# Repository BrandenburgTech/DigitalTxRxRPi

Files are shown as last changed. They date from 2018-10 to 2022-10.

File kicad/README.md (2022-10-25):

v1_3 - Digital Transceiver for the Raspberry Pi with the AX5043

v1_3_5 - Digital Transceiver for the Raspberry Pi with the AX5243

v2_0 - Digital Transceiver for the Raspberry Pi with the AX5043, power amplifier, and GPS module

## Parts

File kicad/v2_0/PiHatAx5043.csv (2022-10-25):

Source: | /home/jbrandenburg/src/git/maker/PiHatAx5043/kicad/PiHatAx5043.sch
Date: | Fri 19 Oct 2018 04:19:05 PM CDT
Tool: | Eeschema 5.0.1-33cea8e~67~ubuntu18.04.1
Generator: | /usr/share/kicad/plugins/bom_csv_grouped_by_value.py
Component Count: | 78
Individual Components:
Item | Qty | Reference(s) | Value | LibPart | Footprint | Datasheet | Description | Height | Manufacturer_Name | Manufacturer_Part_Number | RS Part Number | Supplier_Name
 |  | C1 | DNP | Device:C | Capacitor_SMD:C_0603_1608Metric
 |  | C2 | DNP | Device:C | Capacitor_SMD:C_0603_1608Metric
 |  | C3 | DNP | Device:C | Capacitor_SMD:C_0603_1608Metric
 |  | C4 | 5p1 | Device:C | Capacitor_SMD:C_0603_1608Metric
 |  | C5 | 11p | Device:C | Capacitor_SMD:C_0603_1608Metric
 |  | C6 | 5p6 | Device:C | Capacitor_SMD:C_0603_1608Metric
 |  | C7 | 4p3 | Device:C | Capacitor_SMD:C_0603_1608Metric
 |  | C8 | 4p3 | Device:C | Capacitor_SMD:C_0603_1608Metric
 |  | C9 | 10n | Device:C | Capacitor_SMD:C_0603_1608Metric
 |  | C10 | 10n | Device:C | Capacitor_SMD:C_0603_1608Metric
 |  | C11 | 10n | Device:C | Capacitor_SMD:C_0603_1608Metric
 |  | C12 | 100n | Device:C | Capacitor_SMD:C_0603_1608Metric
 |  | C13 | 4p3 | Device:C | Capacitor_SMD:C_0603_1608Metric | ~
 |  | C14 | 5p6 | Device:C | Capacitor_SMD:C_0603_1608Metric | ~
 |  | C15 | DNP | Device:C | Capacitor_SMD:C_0603_1608Metric | ~
 |  | C16 | 6p8 | Device:C | Capacitor_SMD:C_0603_1608Metric | ~
 |  | C17 | DNP | Device:C | Capacitor_SMD:C_0603_1608Metric | ~
 |  | C18 | DNP | Device:C | Capacitor_SMD:C_0603_1608Metric | ~
 |  | C19 | DNP | Device:C | Capacitor_SMD:C_0603_1608Metric | ~
 |  | C20 | 100p | Device:C | Capacitor_SMD:C_0603_1608Metric | ~
 |  | C21 | 1u | Device:C | Capacitor_SMD:C_0603_1608Metric | ~
 |  | C22 | 1u | Device:C | Capacitor_SMD:C_0603_1608Metric | ~
 |  | C23 | 470p | Device:C | Capacitor_SMD:C_0603_1608Metric | ~
 |  | C24 | 4u7 | Device:C | Capacitor_SMD:C_0603_1608Metric | ~
 |  | C25 | 3p9 | Device:C | Capacitor_SMD:C_0603_1608Metric | ~
 |  | C26 | 10p | Device:C | Capacitor_SMD:C_0603_1608Metric | ~
 |  | C27 | 3p3 | Device:C | Capacitor_SMD:C_0603_1608Metric | ~
 |  | C28 | 11p | Device:C | Capacitor_SMD:C_0603_1608Metric | ~
 |  | C29 | 3p3 | Device:C | Capacitor_SMD:C_0603_1608Metric | ~
 |  | C30 | 10n | Device:C | Capacitor_SMD:C_0603_1608Metric | ~
 |  | C31 | 47p | Device:C | Capacitor_SMD:C_0603_1608Metric | ~
 |  | C32 | NP | Device:C | Capacitor_SMD:C_0603_1608Metric | ~
 |  | C33 | NP | Device:C | Capacitor_SMD:C_0603_1608Metric | ~
 |  | D1 | LED | Device:LED | LED_SMD:LED_0603_1608Metric
 |  | J1 | Conn_01x02_Male | Connector:Conn_01x02_Male | Connector_PinHeader_2.54mm:PinHeader_1x02_P2.54mm_Vertical | ~
 |  | J2 | Conn_01x02_Male | Connector:Conn_01x02_Male | Connector_PinHeader_2.54mm:PinHeader_1x02_P2.54mm_Vertical | ~
 |  | J3 | Conn_01x02_Male | Connector:Conn_01x02_Male | Connector_PinHeader_2.54mm:PinHeader_1x02_P2.54mm_Vertical | ~
 |  | J4 | Conn_01x02_Male | Connector:Conn_01x02_Male | Connector_PinHeader_2.54mm:PinHeader_1x02_P2.54mm_Vertical | ~
 |  | J5 | Conn_01x03_Male | Connector:Conn_01x03_Male | Connector_PinHeader_2.54mm:PinHeader_1x03_P2.54mm_Vertical | ~
 |  | J6 | Conn_01x02_Male | Connector:Conn_01x02_Male | Connector_PinHeader_2.54mm:PinHeader_1x02_P2.54mm_Vertical | ~
 |  | L1 | 0R | Device:L | Inductor_SMD:L_0603_1608Metric
 |  | L2 | 27n | Device:L | Inductor_SMD:L_0603_1608Metric
 |  | L3 | 27n | Device:L | Inductor_SMD:L_0603_1608Metric
 |  | L4 | 43n | Device:L | Inductor_SMD:L_0603_1608Metric
 |  | L5 | 43n | Device:L | Inductor_SMD:L_0603_1608Metric
 |  | L6 | 100n | Device:L | Inductor_SMD:L_0603_1608Metric
 |  | L7 | 100n | Device:L | Inductor_SMD:L_0603_1608Metric
 |  | L8 | 0R | Device:L | Inductor_SMD:L_0603_1608Metric
 |  | L9 | 43n | Device:L | Inductor_SMD:L_0603_1608Metric | ~
 |  | L10 | 100n | Device:L | Inductor_SMD:L_0603_1608Metric | ~
 |  | L11 | 4n7 | Device:L | Inductor_SMD:L_0603_1608Metric | ~
 |  | L12 | 0R | Device:L | Inductor_SMD:L_0603_1608Metric | ~
 |  | L13 | 18n | Device:L | Inductor_SMD:L_0603_1608Metric | ~
 |  | L14 | 1n2 | Device:L | Inductor_SMD:L_0603_1608Metric | ~
 |  | L15 | 12n | Device:L | Inductor_SMD:L_0603_1608Metric | ~
 |  | L16 | 3n9 | Device:L | Inductor_SMD:L_0603_1608Metric | ~
 |  | L17 | 12n | Device:L | Inductor_SMD:L_0603_1608Metric | ~
 |  | L18 | 22n | Device:L | Inductor_SMD:L_0603_1608Metric | ~
 |  | L19 | 22n | Device:L | Inductor_SMD:L_0603_1608Metric | ~
 |  | L20 | 27n | Device:L | Inductor_SMD:L_0603_1608Metric | ~
 |  | P1 | SMA | Connector:Conn_Coaxial | Connector_Coaxial:SMA_Amphenol_901-144_Vertical
 |  | P2 | CONN_13X2 | Connector_Generic:Conn_02x13_Odd_Even | Connector_PinHeader_2.54mm:PinHeader_2x13_P2.54mm_Vertical
 |  | P3 | CONN_01X06 | Connector:Conn_01x06_Male | Connector_PinHeader_2.54mm:PinHeader_1x06_P2.54mm_Vertical
 |  | P4 | SMA | Connector:Conn_Coaxial | Connector_Coaxial:SMA_Amphenol_901-144_Vertical
 |  | P5 | SMA | Connector:Conn_Coaxial | Connector_Coaxial:SMA_Amphenol_901-144_Vertical
 |  | R1 | 0R | Device:R | Resistor_SMD:R_0603_1608Metric
 |  | R2 | 0R | Device:R | Resistor_SMD:R_0603_1608Metric
 |  | R3 | 4k7 | Device:R | Resistor_SMD:R_0603_1608Metric
 |  | R4 | 4k7 | Device:R | Resistor_SMD:R_0603_1608Metric
 |  | R5 | 200 | Device:R | Resistor_SMD:R_0603_1608Metric
 |  | R6 | 330 | Device:R | Resistor_SMD:R_0603_1608Metric | ~
 |  | R7 | 1k5 | Device:R | Resistor_SMD:R_0603_1608Metric | ~
 |  | R8 | 10 | Device:R | Resistor_SMD:R_0603_1608Metric | ~
 |  | U1 | AX5043 | ax5043:AX5043-1-TA05 | ax5043:QFN50P500X500X95-29N | http://docs-europe.electrocomponents.com/webdocs/14ae/0900766b814aed64.pdf | AX5043 27-1050MHz RF Transceiver AX5043-1-TA05, RF Transceiver 27 1050MHz, AFSK, ASK, FM, FSK, GFSK, GMSK, MSK, PSK, QFSK, 1.8 3.6 V | 0.95 | ON Semiconductor | AX5043-1-TA05 | 1249950 | RS
 |  | U2 | MAX31725 | max31725:MAX31725 | Package_DFN_QFN:DFN-8-1EP_3x3mm_P0.65mm_EP1.55x2.4mm
 |  | U3 | MMZ09312BT1 | nxp:MMZ09312BT1 | Package_DFN_QFN:QFN-12-1EP_3x3mm_P0.5mm_EP1.65x1.65mm_ThermalVias
 |  | U4 | MAX-M8 | ublox:MAX-M8 | MAX-M8:MAX-M8
 |  | Y1 | 16M | Device:Crystal_GND24 | ecx-42-smd-crystal:Crystal_SMD_ECX42-4pin_4.0x2.5mm
Collated Components:
Item | Qty | Reference(s) | Value | LibPart | Footprint | Datasheet | Description | Height | Manufacturer_Name | Manufacturer_Part_Number | RS Part Number | Supplier_Name
1 | 7 | C1, C2, C3, C15, C17, C18, C19 | DNP | Device:C | Capacitor_SMD:C_0603_1608Metric | ~
2 | 1 | C4 | 5p1 | Device:C | Capacitor_SMD:C_0603_1608Metric
3 | 2 | C5, C28 | 11p | Device:C | Capacitor_SMD:C_0603_1608Metric | ~
4 | 2 | C6, C14 | 5p6 | Device:C | Capacitor_SMD:C_0603_1608Metric | ~
5 | 3 | C7, C8, C13 | 4p3 | Device:C | Capacitor_SMD:C_0603_1608Metric | ~
6 | 4 | C9, C10, C11, C30 | 10n | Device:C | Capacitor_SMD:C_0603_1608Metric | ~
7 | 1 | C12 | 100n | Device:C | Capacitor_SMD:C_0603_1608Metric
8 | 1 | C16 | 6p8 | Device:C | Capacitor_SMD:C_0603_1608Metric | ~
9 | 1 | C20 | 100p | Device:C | Capacitor_SMD:C_0603_1608Metric | ~
10 | 2 | C21, C22 | 1u | Device:C | Capacitor_SMD:C_0603_1608Metric | ~
11 | 1 | C23 | 470p | Device:C | Capacitor_SMD:C_0603_1608Metric | ~
12 | 1 | C24 | 4u7 | Device:C | Capacitor_SMD:C_0603_1608Metric | ~
13 | 1 | C25 | 3p9 | Device:C | Capacitor_SMD:C_0603_1608Metric | ~
14 | 1 | C26 | 10p | Device:C | Capacitor_SMD:C_0603_1608Metric | ~
15 | 2 | C27, C29 | 3p3 | Device:C | Capacitor_SMD:C_0603_1608Metric | ~
16 | 1 | C31 | 47p | Device:C | Capacitor_SMD:C_0603_1608Metric | ~
17 | 2 | C32, C33 | NP | Device:C | Capacitor_SMD:C_0603_1608Metric | ~
18 | 1 | D1 | LED | Device:LED | LED_SMD:LED_0603_1608Metric
19 | 5 | J1, J2, J3, J4, J6 | Conn_01x02_Male | Connector:Conn_01x02_Male | Connector_PinHeader_2.54mm:PinHeader_1x02_P2.54mm_Vertical | ~
20 | 1 | J5 | Conn_01x03_Male | Connector:Conn_01x03_Male | Connector_PinHeader_2.54mm:PinHeader_1x03_P2.54mm_Vertical | ~
21 | 3 | L1, L8, L12 | 0R | Device:L | Inductor_SMD:L_0603_1608Metric | ~
22 | 3 | L2, L3, L20 | 27n | Device:L | Inductor_SMD:L_0603_1608Metric | ~
23 | 3 | L4, L5, L9 | 43n | Device:L | Inductor_SMD:L_0603_1608Metric | ~
24 | 3 | L6, L7, L10 | 100n | Device:L | Inductor_SMD:L_0603_1608Metric | ~
25 | 1 | L11 | 4n7 | Device:L | Inductor_SMD:L_0603_1608Metric | ~
26 | 1 | L13 | 18n | Device:L | Inductor_SMD:L_0603_1608Metric | ~
27 | 1 | L14 | 1n2 | Device:L | Inductor_SMD:L_0603_1608Metric | ~
28 | 2 | L15, L17 | 12n | Device:L | Inductor_SMD:L_0603_1608Metric | ~
29 | 1 | L16 | 3n9 | Device:L | Inductor_SMD:L_0603_1608Metric | ~
30 | 2 | L18, L19 | 22n | Device:L | Inductor_SMD:L_0603_1608Metric | ~
31 | 3 | P1, P4, P5 | SMA | Connector:Conn_Coaxial | Connector_Coaxial:SMA_Amphenol_901-144_Vertical
32 | 1 | P2 | CONN_13X2 | Connector_Generic:Conn_02x13_Odd_Even | Connector_PinHeader_2.54mm:PinHeader_2x13_P2.54mm_Vertical
33 | 1 | P3 | CONN_01X06 | Connector:Conn_01x06_Male | Connector_PinHeader_2.54mm:PinHeader_1x06_P2.54mm_Vertical
34 | 2 | R1, R2 | 0R | Device:R | Resistor_SMD:R_0603_1608Metric
35 | 2 | R3, R4 | 4k7 | Device:R | Resistor_SMD:R_0603_1608Metric
36 | 1 | R5 | 200 | Device:R | Resistor_SMD:R_0603_1608Metric
37 | 1 | R6 | 330 | Device:R | Resistor_SMD:R_0603_1608Metric | ~
38 | 1 | R7 | 1k5 | Device:R | Resistor_SMD:R_0603_1608Metric | ~
39 | 1 | R8 | 10 | Device:R | Resistor_SMD:R_0603_1608Metric | ~
40 | 1 | U1 | AX5043 | ax5043:AX5043-1-TA05 | ax5043:QFN50P500X500X95-29N | http://docs-europe.electrocomponents.com/webdocs/14ae/0900766b814aed64.pdf | AX5043 27-1050MHz RF Transceiver AX5043-1-TA05, RF Transceiver 27 1050MHz, AFSK, ASK, FM, FSK, GFSK, GMSK, MSK, PSK, QFSK, 1.8 3.6 V | 0.95 | ON Semiconductor | AX5043-1-TA05 | 1249950 | RS
41 | 1 | U2 | MAX31725 | max31725:MAX31725 | Package_DFN_QFN:DFN-8-1EP_3x3mm_P0.65mm_EP1.55x2.4mm
42 | 1 | U3 | MMZ09312BT1 | nxp:MMZ09312BT1 | Package_DFN_QFN:QFN-12-1EP_3x3mm_P0.5mm_EP1.65x1.65mm_ThermalVias
43 | 1 | U4 | MAX-M8 | ublox:MAX-M8 | MAX-M8:MAX-M8
44 | 1 | Y1 | 16M | Device:Crystal_GND24 | ecx-42-smd-crystal:Crystal_SMD_ECX42-4pin_4.0x2.5mm

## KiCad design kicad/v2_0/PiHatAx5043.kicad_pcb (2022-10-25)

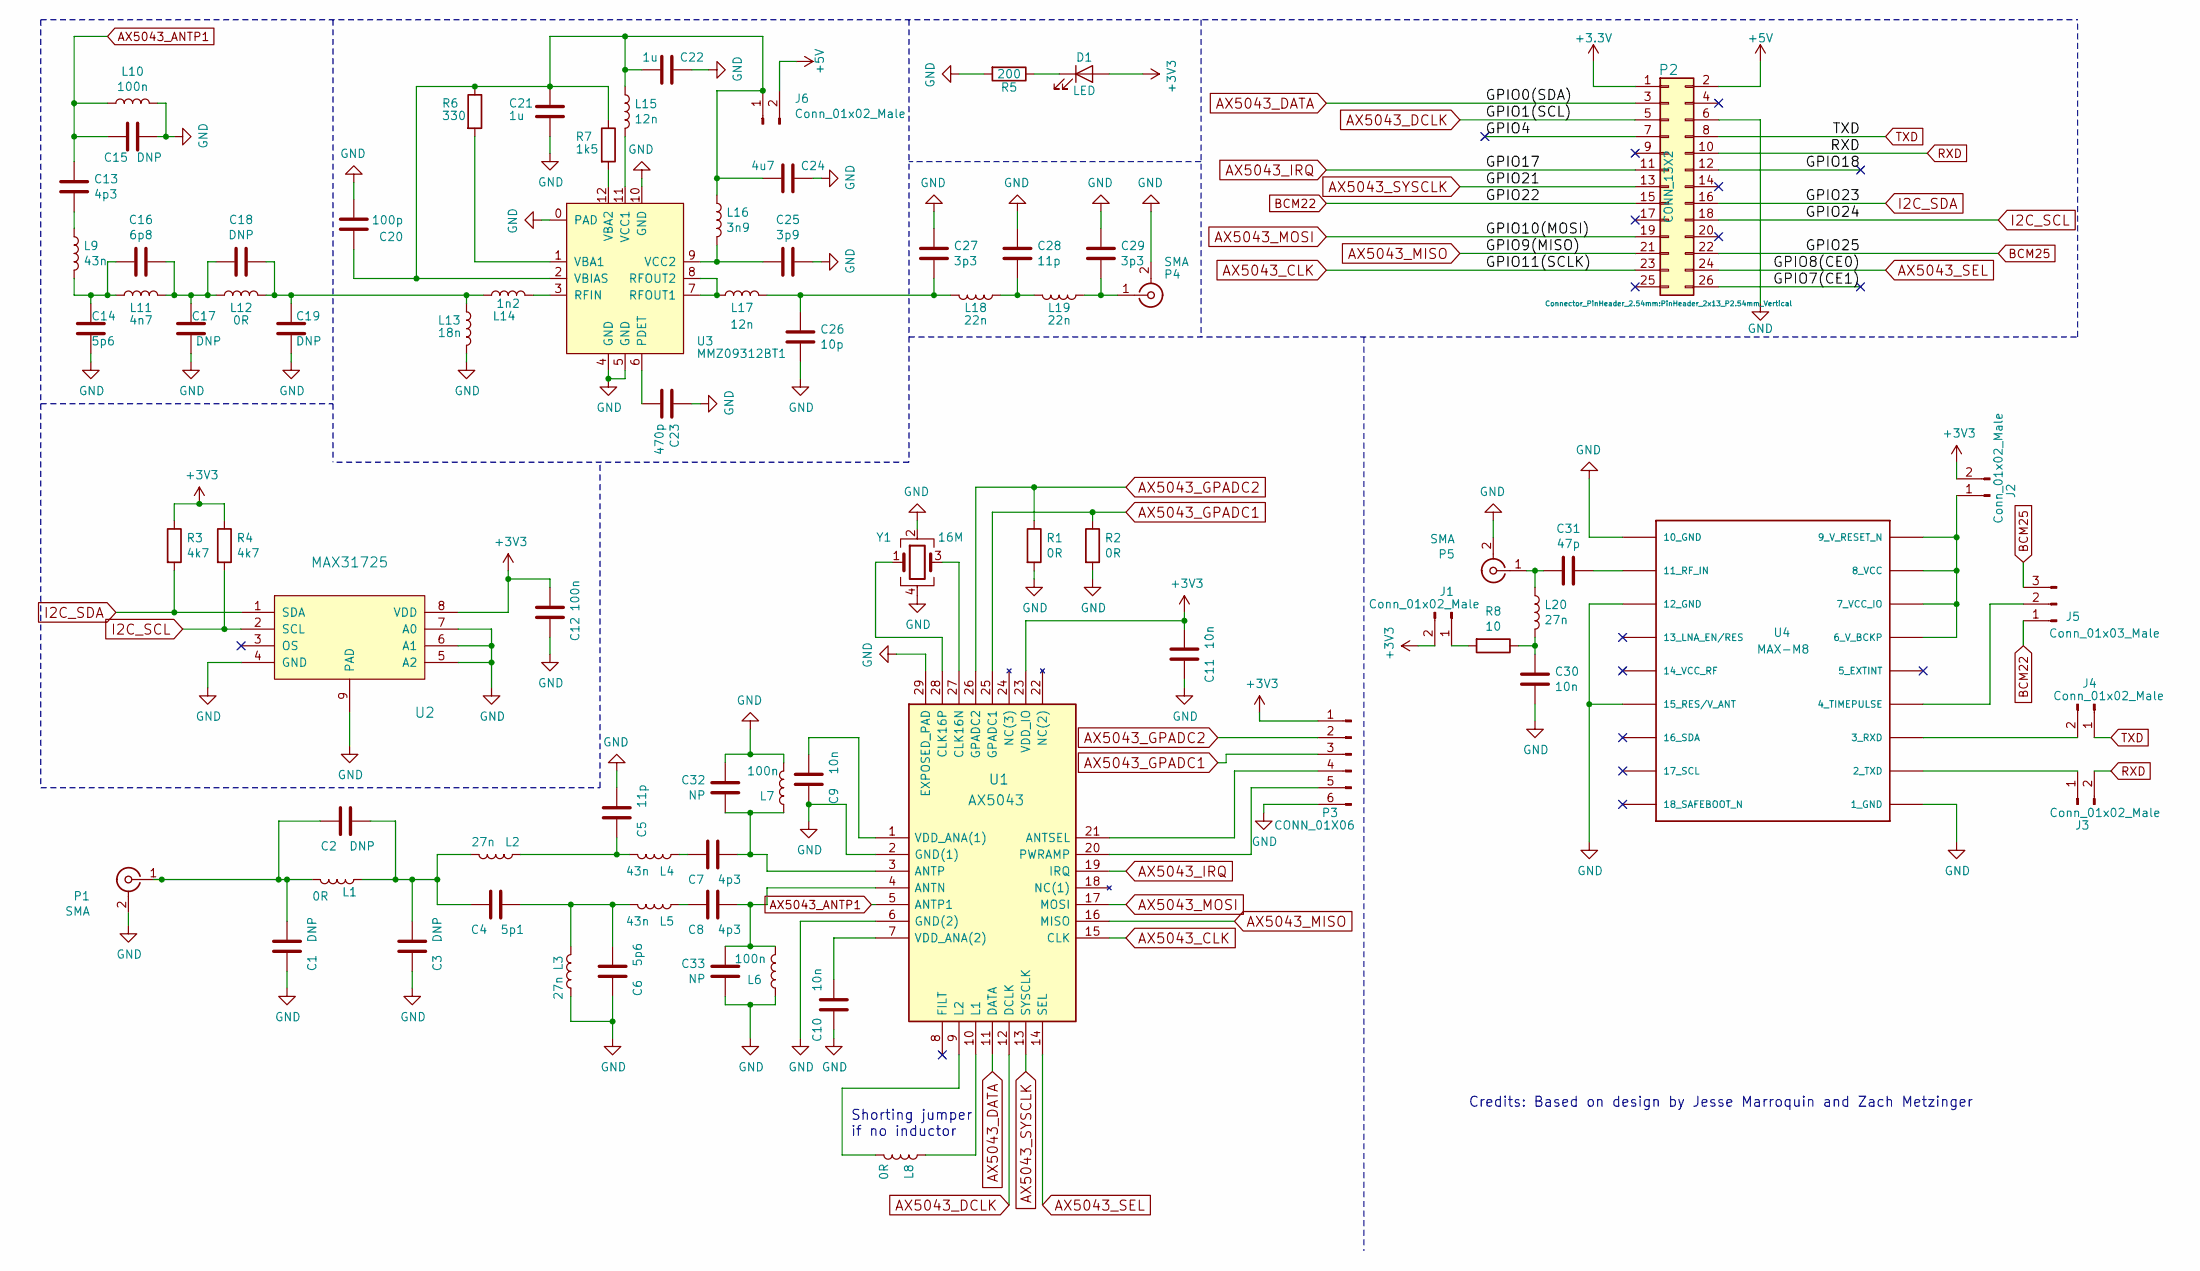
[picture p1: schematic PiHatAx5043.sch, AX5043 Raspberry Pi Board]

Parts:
C1, C2, C3, C15, C17, C18, C19: DNP; C_0603_1608Metric
C4: 5p1; C_0603_1608Metric
C5, C28: 11p; C_0603_1608Metric
C6, C14: 5p6; C_0603_1608Metric
C7, C8, C13: 4p3; C_0603_1608Metric
C9, C10, C11, C30: 10n; C_0603_1608Metric
C12: 100n; C_0603_1608Metric
C16: 6p8; C_0603_1608Metric
C20: 100p; C_0603_1608Metric
C21, C22: 1u; C_0603_1608Metric
C23: 470p; C_0603_1608Metric
C24: 4u7; C_0603_1608Metric
C25: 3p9; C_0603_1608Metric
C26: 10p; C_0603_1608Metric
C27, C29: 3p3; C_0603_1608Metric
C31: 47p; C_0603_1608Metric
C32, C33: NP; C_0603_1608Metric
D1: LED; LED_0603_1608Metric
J1, J2, J3, J4, J6: Conn_01x02_Male; PinHeader_1x02_P2.54mm_Vertical
J5: Conn_01x03_Male; PinHeader_1x03_P2.54mm_Vertical
L1, L8, L12: 0R; L_0603_1608Metric
L2, L3, L20: 27n; L_0603_1608Metric
L4, L5, L9: 43n; L_0603_1608Metric
L6, L7, L10: 100n; L_0603_1608Metric
L11: 4n7; L_0603_1608Metric
L13: 18n; L_0603_1608Metric
L14: 1n2; L_0603_1608Metric
L15, L17: 12n; L_0603_1608Metric
L16: 3n9; L_0603_1608Metric
L18, L19: 22n; L_0603_1608Metric
P1, P4, P5: SMA; SMA_Amphenol_901-144_Vertical
P2: CONN_13X2; PinHeader_2x13_P2.54mm_Vertical
P3: CONN_01X06; PinHeader_1x06_P2.54mm_Vertical
R1, R2: 0R; R_0603_1608Metric
R3, R4: 4k7; R_0603_1608Metric
R5: 200; R_0603_1608Metric
R6: 330; R_0603_1608Metric
R7: 1k5; R_0603_1608Metric
R8: 10; R_0603_1608Metric
U1: AX5043; QFN50P500X500X95-29N
U2: MAX31725; DFN-8-1EP_3x3mm_P0.65mm_EP1.55x2.4mm
U3: MMZ09312BT1; QFN-12-1EP_3x3mm_P0.5mm_EP1.65x1.65mm_ThermalVias
U4: MAX-M8
Y1: 16M; Crystal_SMD_ECX42-4pin_4.0x2.5mm

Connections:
+5V: J6.2, P2.2
/GPIO4: P2.7
/GPIO7(CE1): P2.26
/GPIO18: P2.12
AX5043_ANTP1: C13.1, C15.2, L10.1, U1.5 (ANTP1)
AX5043_CLK: P2.23, U1.15 (CLK)
AX5043_DATA: P2.3, U1.11 (DATA)
AX5043_DCLK: P2.5, U1.12 (DCLK)
AX5043_GPADC1: P3.3, R2.1, U1.25 (GPADC1)
AX5043_GPADC2: P3.2, R1.1, U1.26 (GPADC2)
AX5043_IRQ: P2.11, U1.19 (IRQ)
AX5043_MISO: P2.21, U1.16 (MISO)
AX5043_MOSI: P2.19, U1.17 (MOSI)
AX5043_SEL: P2.24, U1.14 (SEL)
AX5043_SYSCLK: P2.13, U1.13 (SYSCLK)
BCM22: J5.1, P2.15
BCM25: J5.3, P2.22
GND: C1.2, C3.2, C5.1, C6.2, C9.2, C10.2, C11.2, C12.2, C14.2, C15.1, C17.2, C19.2, C20.2, C21.2, C22.1, C23.1, C24.1, C25.1, C26.2, C27.1, C28.1, C29.1, C30.2, C32.2, C33.1, L3.1, L6.1, L7.2, L10.2, L13.2, P1.2 (Ext), P2.6, P3.6, P4.2 (Ext), P5.2 (Ext), R1.2, R2.2, R5.2, U1.2 (GND(1)), U1.6 (GND(2)), U1.29 (EXPOSED_PAD), U2.4 (GND), U2.5 (A2), U2.6 (A1), U2.7 (A0), U2.9 (PAD), U3.0 (PAD), U3.4 (GND), U3.5 (GND), U3.10 (GND), U3.13, U4.1_GND, U4.10_GND, U4.12_GND, U4.15_V_ANT/RESERVED (15_RES/V_ANT), Y1.2, Y1.4
I2C_SCL: P2.18, R4.2, U2.2 (SCL)
I2C_SDA: P2.16, R3.2, U2.1 (SDA)
unnamed: C1.1, C2.2, L1.2, P1.1 (In)
unnamed: C2.1, C3.1, C4.2, L1.1, L2.2
unnamed: C4.1, C6.1, L3.2, L5.2
unnamed: C5.2, L2.1, L4.2
unnamed: C7.2, L4.1
unnamed: C8.2, L5.1
unnamed: C9.1, U1.1 (VDD_ANA(1))
unnamed: C10.1, U1.7 (VDD_ANA(2))
unnamed: C13.2, L9.1
unnamed: C14.1, C16.2, L9.2, L11.1
unnamed: C16.1, C17.1, C18.2, L11.2, L12.1
unnamed: C18.1, C19.1, L12.2, L13.1, L14.1
unnamed: C20.1, C21.1, C22.2, C24.2, J6.1, L15.1, L16.1, R6.1, R7.1, U3.2 (VBIAS)
unnamed: C23.2, U3.6 (PDET)
unnamed: C25.2, L16.2, U3.9 (VCC2)
unnamed: C26.1, C27.2, L17.2, L18.2
unnamed: C28.2, L18.1, L19.2
unnamed: C29.2, L19.1, P4.1 (In)
unnamed: C30.1, L20.2, R8.1
unnamed: C31.1, U4.11_RF_IN
unnamed: C31.2, L20.1, P5.1 (In)
unnamed: C7.1, C32.1, L7.1, U1.3 (ANTP)
unnamed: C8.1, C33.2, L6.2, U1.4 (ANTN)
unnamed: D1.1 (K), R5.1
unnamed: J1.1, R8.2
unnamed: J2.1, U4.6_V_BCKP, U4.7_VCC_IO, U4.8_VCC, U4.9_RESET_N (9_V_RESET_N)
unnamed: J3.1, U4.2_TXD
unnamed: J4.2, U4.3_RXD
unnamed: J5.2, U4.4_TIMEPULSE
unnamed: L8.1, U1.10 (L1)
unnamed: L8.2, U1.9 (L2)
unnamed: L14.2, U3.3 (RFIN)
unnamed: L15.2, U3.11 (VCC1)
unnamed: L17.1, U3.7 (RFOUT1), U3.8 (RFOUT2)
unnamed: P3.4, U1.21 (ANTSEL)
unnamed: P3.5, U1.20 (PWRAMP)
unnamed: R6.2, U3.1 (VBA1)
unnamed: R7.2, U3.12 (VBA2)
unnamed: U1.27 (CLK16N), Y1.3
unnamed: U1.28 (CLK16P), Y1.1
RXD: J3.2, P2.10
TXD: J4.1, P2.8

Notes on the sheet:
Shorting jumper if no inductor
Credits: Based on design by Jesse Marroquin and Zach Metzinger

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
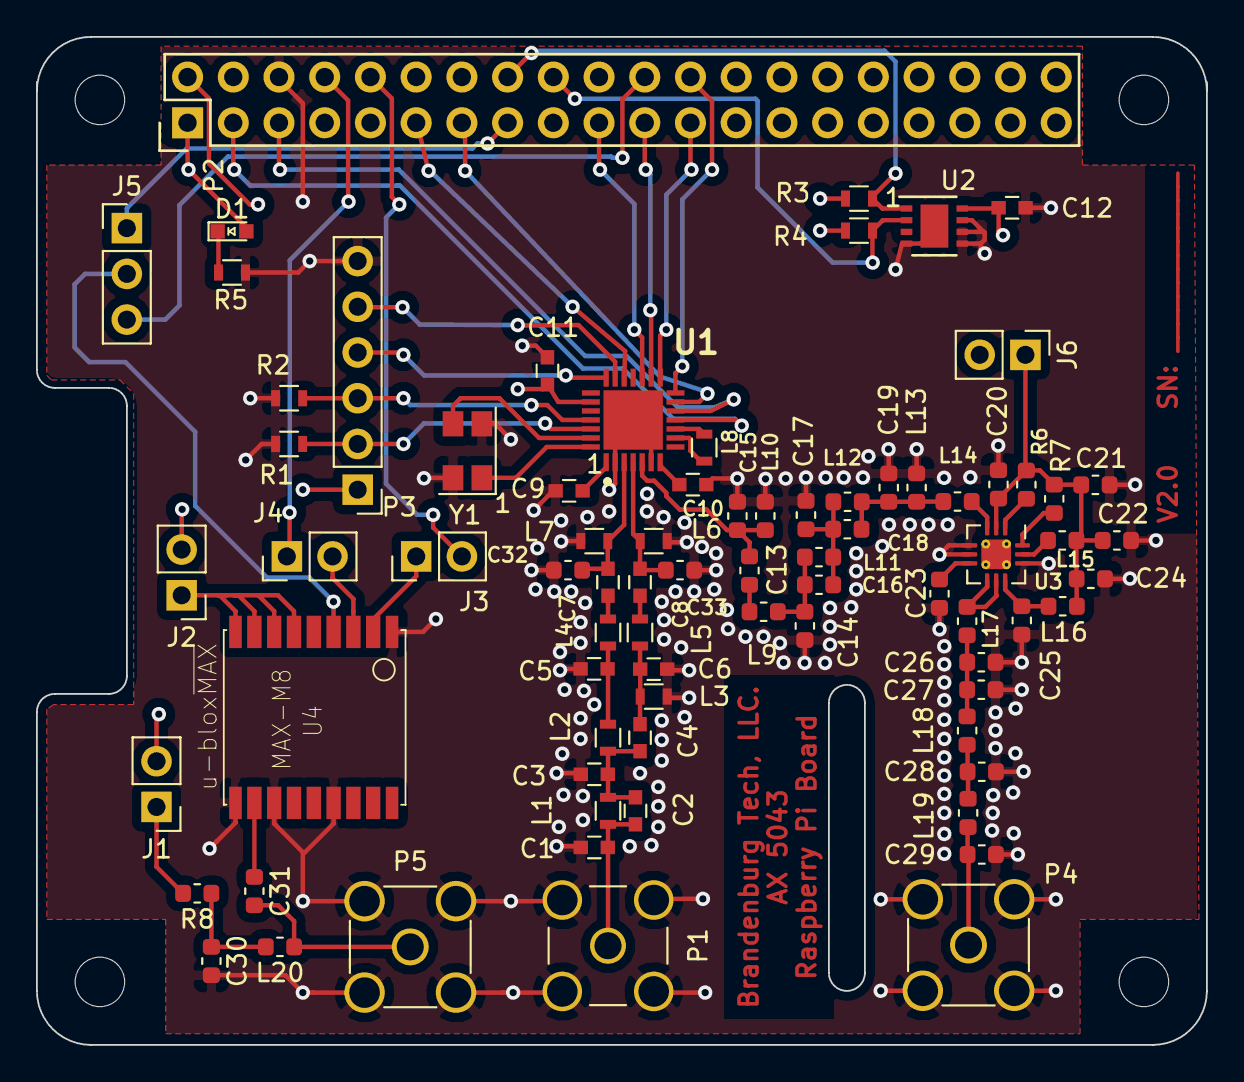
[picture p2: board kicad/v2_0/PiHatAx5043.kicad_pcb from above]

Board: 4 copper layers, 65.0 x 56.0 mm, 78 parts (0 on the bottom side), 60 nets.

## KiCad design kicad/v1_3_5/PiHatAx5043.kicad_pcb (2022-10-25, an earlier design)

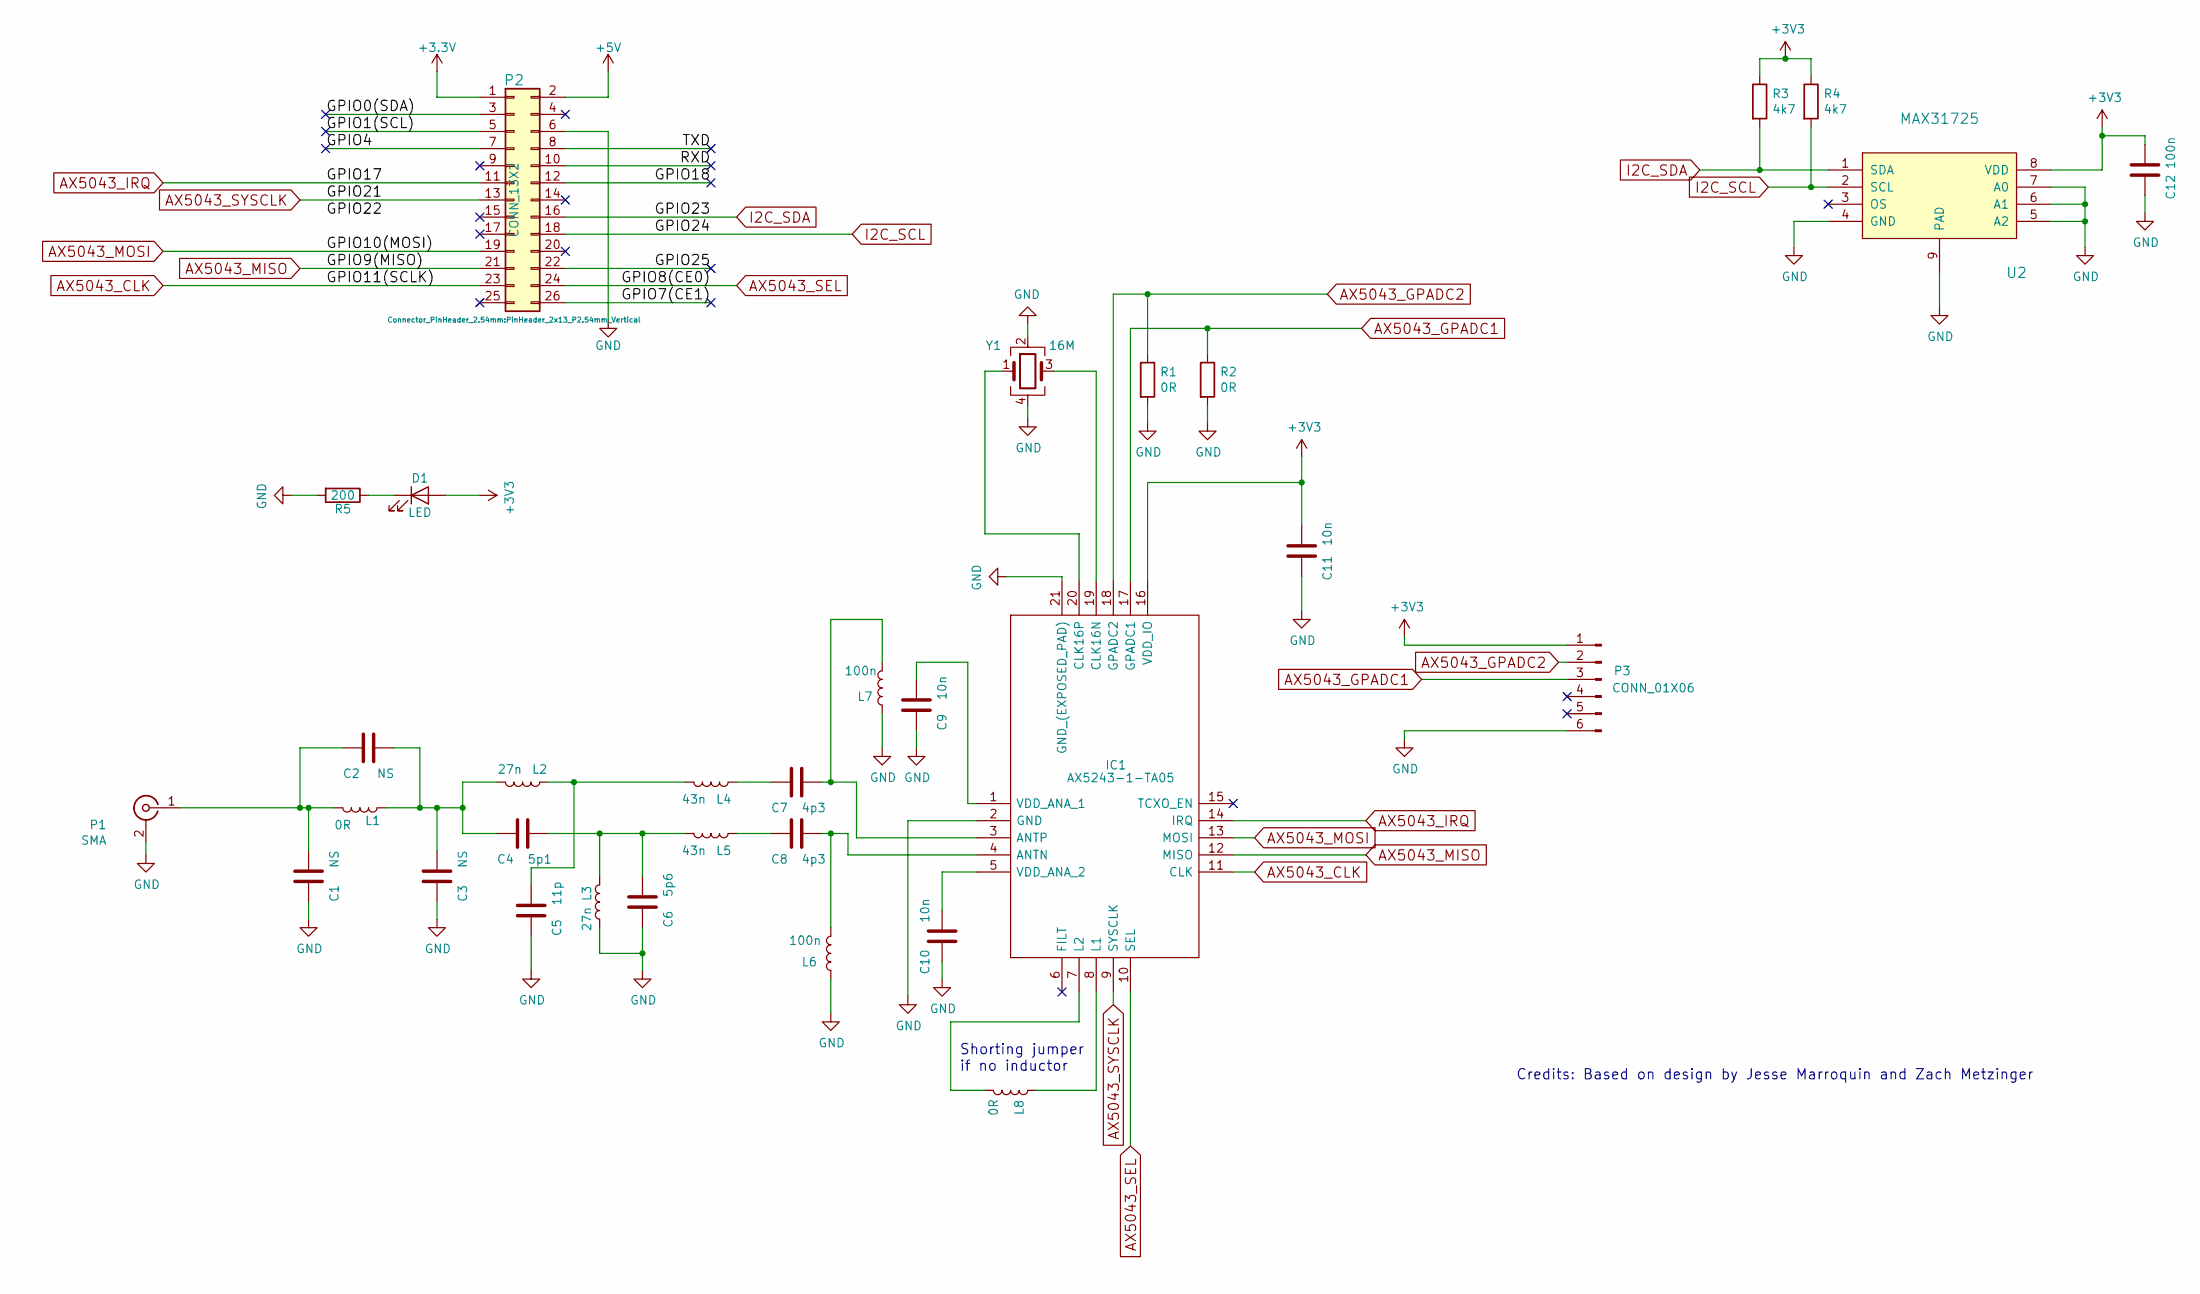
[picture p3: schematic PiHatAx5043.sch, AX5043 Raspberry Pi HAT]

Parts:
C1, C2, C3: NS; C_0603_1608Metric
C4: 5p1; C_0603_1608Metric
C5: 11p; C_0603_1608Metric
C6: 5p6; C_0603_1608Metric
C7, C8: 4p3; C_0603_1608Metric
C9, C10, C11: 10n; C_0603_1608Metric
C12: 100n; C_0603_1608Metric
D1: LED; LED_0603_1608Metric
IC1: AX5243-1-TA05; QFN50P400X400X100-21N; Manufacturer_Part_Number AX5243-1-TA05; Mouser Part Number 863-AX5243-1-TA05
L1, L8: 0R; L_0603_1608Metric
L2, L3: 27n; L_0603_1608Metric
L4, L5: 43n; L_0603_1608Metric
L6, L7: 100n; L_0603_1608Metric
P1: SMA; SMA_Amphenol_901-144_Vertical
P2: CONN_13X2; PinHeader_2x13_P2.54mm_Vertical
P3: CONN_01X06; PinHeader_1x06_P2.54mm_Vertical
R1, R2: 0R; R_0603_1608Metric
R3, R4: 4k7; R_0603_1608Metric
R5: 200; R_0603_1608Metric
U2: MAX31725; DFN-8-1EP_3x3mm_P0.65mm_EP1.55x2.4mm
Y1: 16M; Crystal_SMD_ECX42-4pin_4.0x2.5mm

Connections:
+5V: P2.2
/GPIO0(SDA): P2.3
/GPIO1(SCL): P2.5
/GPIO4: P2.7
/GPIO7(CE1): P2.26
/GPIO18: P2.12
/GPIO25: P2.22
/RXD: P2.10
/TXD: P2.8
AX5043_CLK: IC1.11 (CLK), P2.23
AX5043_GPADC1: IC1.17 (GPADC1), P3.3, R2.1
AX5043_GPADC2: IC1.18 (GPADC2), P3.2, R1.1
AX5043_IRQ: IC1.14 (IRQ), P2.11
AX5043_MISO: IC1.12 (MISO), P2.21
AX5043_MOSI: IC1.13 (MOSI), P2.19
AX5043_SEL: IC1.10 (SEL), P2.24
AX5043_SYSCLK: IC1.9 (SYSCLK), P2.13
GND: C1.2, C3.2, C5.2, C6.2, C9.2, C10.2, C11.2, C12.2, IC1.2 (GND), IC1.21 (GND_(EXPOSED_PAD)), L3.1, L6.1, L7.1, P1.2 (Ext), P2.6, P3.6, R1.2, R2.2, R5.2, U2.4 (GND), U2.5 (A2), U2.6 (A1), U2.7 (A0), U2.9 (PAD), Y1.2, Y1.4
I2C_SCL: P2.18, R4.2, U2.2 (SCL)
I2C_SDA: P2.16, R3.2, U2.1 (SDA)
unnamed: C1.1, C2.2, L1.2, P1.1 (In)
unnamed: C2.1, C3.1, C4.2, L1.1, L2.2
unnamed: C4.1, C6.1, L3.2, L5.2
unnamed: C5.1, L2.1, L4.2
unnamed: C7.1, IC1.3 (ANTP), L7.2
unnamed: C7.2, L4.1
unnamed: C8.1, IC1.4 (ANTN), L6.2
unnamed: C8.2, L5.1
unnamed: C9.1, IC1.1 (VDD_ANA_1)
unnamed: C10.1, IC1.5 (VDD_ANA_2)
unnamed: D1.1 (K), R5.1
unnamed: IC1.7 (L2), L8.2
unnamed: IC1.8 (L1), L8.1
unnamed: IC1.19 (CLK16N), Y1.3
unnamed: IC1.20 (CLK16P), Y1.1

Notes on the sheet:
Shorting jumper if no inductor
Credits: Based on design by Jesse Marroquin and Zach Metzinger

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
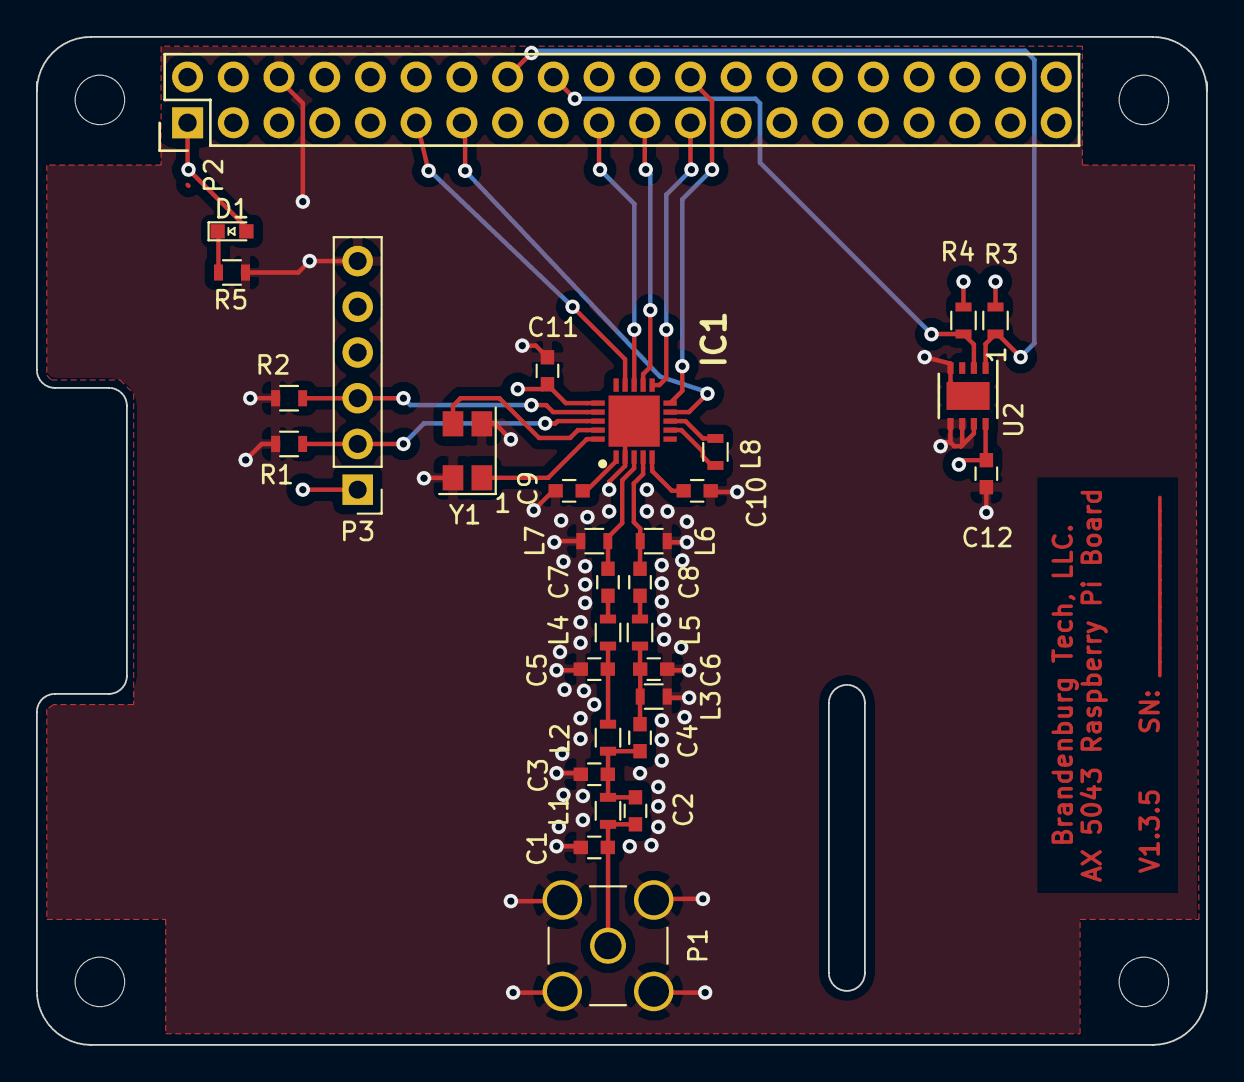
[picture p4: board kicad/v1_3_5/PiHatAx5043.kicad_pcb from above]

Board: 4 copper layers, 65.0 x 56.0 mm, 32 parts (0 on the bottom side), 27 nets.

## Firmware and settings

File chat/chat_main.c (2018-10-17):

/*
 *  Copyright (C) 2018 Jonathan Brandenburg
 *
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
 *  You should have received a copy of the GNU General Public License
 *  along with this program.  If not, see <http://www.gnu.org/licenses/>.
 */

#include <axradio/axradioinit_p.h>
#include <axradio/axradiomode_p.h>
#include <axradio/axradiorx_p.h>
#include <axradio/axradiotx_p.h>
#include <generated/configtx.h>
#include <pthread.h>
#include <semaphore.h>
#include <spi/ax5043spi_p.h>
#include <stdint.h>
#include <stdio.h>
#include <stdlib.h>
#include <string.h>
#include <unistd.h>
#include <errno.h>

#define MAX_MESSAGE_LENGTH (197)

extern uint8_t axradio_rxbuffer[];

void *receive(void *arg);
void *transmit(void *arg);
size_t get_message(uint8_t *buffer, size_t avail);

enum RadioState {UnknownState, RxState, TxState};
enum RadioState currentState = UnknownState;

enum ReceiveState {WaitingForNewPacket, WaitingForPacketCounter1,
   WaitingForPacketCounter2, WaitingForMessageLength1,
   WaitingForMessageLength2, WaitingForMessage,
   WaitingForChecksum1, WaitingForChecksum2};

int main(void)
{
    uint8_t retVal;

    // Configure SPI bus to AX5043
    setSpiChannel(SPI_CHANNEL);
    setSpiSpeed(SPI_SPEED);
    initializeSpi();

    // Initialize the AX5043
    retVal = axradio_init();
    if (retVal == AXRADIO_ERR_NOCHIP) {
        fprintf(stderr, "ERROR: No AX5043 RF chip found\n");
        exit(EXIT_FAILURE);
    }
    if (retVal != AXRADIO_ERR_NOERROR) {
        fprintf(stderr, "ERROR: Unable to initialize AX5043\n");
        exit(EXIT_FAILURE);
    }

    printf("INFO: Found and initialized AX5043\n");

    int result;

    sem_t ax5043_sem;
    result = sem_init(&ax5043_sem, 0, 1);
    if (result != 0) {
        fprintf(stderr, "ERROR: Unable to create semaphore with error %s\n", strerror(errno));
        exit(EXIT_FAILURE);
    }


    pthread_t receive_thread;
    result = pthread_create(&receive_thread, NULL, receive, (void *)&ax5043_sem);
    if (result != 0) {
        fprintf(stderr, "ERROR: Unable to spawn receive thread with error %s\n", strerror(errno));
        exit(EXIT_FAILURE);
    }

    pthread_t transmit_thread;
    result = pthread_create(&transmit_thread, NULL, transmit, (void *)&ax5043_sem);
    if (result != 0) {
        fprintf(stderr, "ERROR: Unable to spawn transmit thread with error %s\n", strerror(errno));
        exit(EXIT_FAILURE);
    }


    void *transmit_result;
    result = pthread_join(transmit_thread, &transmit_result);
    if (result != 0) {
        fprintf(stderr, "ERROR: Unable to wait for transmit thread to finish with error %s\n", strerror(errno));
        exit(EXIT_FAILURE);
    }

    sem_destroy(&ax5043_sem);

    return 0;
}

void *receive(void *arg) {
    sem_t *sem;
    sem = (sem_t *)arg;

    uint8_t retVal;
    uint16_t packetNumber;
    uint16_t messageLength;
    uint16_t checksum;
    char ch;

    enum ReceiveState currentReceiveState = WaitingForNewPacket;

    for (;;) {
        int result;

        result = sem_wait(sem);
        if (result != 0) {
            fprintf(stderr, "Failed to wait on semaphore with error %s\n", strerror(errno));
            exit(EXIT_FAILURE);
        }


        // Enter receive mode only if not already in receive mode
        if (currentState != RxState) {
            retVal = mode_rx();
            if (retVal != AXRADIO_ERR_NOERROR) {
                fprintf(stderr, "ERROR: Unable to enter RX mode\n");
                exit(EXIT_FAILURE);
            }
            currentState = RxState;
        }

        retVal = receive_packet();
        if (retVal > 0) {
            uint8_t counter = 0;
            while (retVal-- > 0) {
                switch(currentReceiveState) {
                case WaitingForNewPacket:
                    printf("Pkt Len: %d ", (int)axradio_rxbuffer[counter++]);
                    currentReceiveState = WaitingForPacketCounter1;
                    break;
                case WaitingForPacketCounter1:
                    packetNumber =  (int)axradio_rxbuffer[counter++];
                    currentReceiveState = WaitingForPacketCounter2;
                    break;
                case WaitingForPacketCounter2:
                    packetNumber |= (uint16_t)(axradio_rxbuffer[counter++] << 8);
                    printf("Pkt Num: %d ", (int)packetNumber);
                    currentReceiveState = WaitingForMessageLength1;
                    break;
                case WaitingForMessageLength1:
                    messageLength =  (int)axradio_rxbuffer[counter++];
                    currentReceiveState = WaitingForMessageLength2;
                    break;
                case WaitingForMessageLength2:
                    messageLength |= (uint16_t)(axradio_rxbuffer[counter++] << 8);
                    printf("Msg Len: %d ", (int)messageLength);
                    currentReceiveState = WaitingForMessage;
                    break;
                case WaitingForMessage:
                    ch = (char)axradio_rxbuffer[counter++];
                    if (ch != '\n') {
                        printf("%c", ch);
                    }
                    else {
                        printf(" ");
                        currentReceiveState = WaitingForChecksum1;
                    }
                    break;
                case WaitingForChecksum1:
                    checksum =  (int)axradio_rxbuffer[counter++];
                    currentReceiveState = WaitingForChecksum2;
                    break;
                case WaitingForChecksum2:
                    checksum |= (uint16_t)(axradio_rxbuffer[counter++] << 8);
                    printf("(Chksum: %d)\n", (int)checksum);
                    currentReceiveState = WaitingForNewPacket;
                    break;
                default:
                    fprintf(stderr, "ERROR: Unknown state in receive state machine\n");
                    exit(EXIT_FAILURE);
                    break;
                }
            }

            fflush(stdout);

        }

        result = sem_post(sem);
        if (result != 0) {
            fprintf(stderr, "Failed to post on semaphore with error %s\n", strerror(errno));
            exit(EXIT_FAILURE);
        }

        usleep(25000);
    }

    return NULL;
}

void *transmit(void *arg) {
    sem_t *sem;
    sem = (sem_t *)arg;

    uint8_t retVal;

    for (;;) {
        int result;

        // allocate space for the buffer
        static uint8_t packet[MAX_MESSAGE_LENGTH + 1];
        uint16_t pkt_counter;

        ++pkt_counter;

        // Calculate the number of reserved bytes at the beginning of the packet
        size_t reserved_space = 0;

        // if transmitting a packet counter, reserve two bytes
        if (framing_insert_counter) {
            reserved_space += 2;
        }

        // reserve two bytes for the overall length of the packet including the
        // packet counter, if present, and the field containing the length
        reserved_space += 2;

        // get a message to transmit.
        size_t msg_length = get_message(&packet[reserved_space], (MAX_MESSAGE_LENGTH + 1) - reserved_space);

        // if message consists only of a newline, terminate
        if (msg_length <= 1) {
            break;
        }

        if (framing_insert_counter) {
            packet[framing_counter_pos] = (uint8_t)(pkt_counter & 0xFF);
            packet[framing_counter_pos+1] = (uint8_t)((pkt_counter>>8) & 0xFF);

            // include the message length
            packet[framing_counter_pos+2] = msg_length & 0xFF ;
            packet[framing_counter_pos+3] = (msg_length>>8) & 0xFF;
        }
        else { // only include the message length
            packet[framing_counter_pos] = msg_length & 0xFF ;
            packet[framing_counter_pos+1] = (msg_length>>8) & 0xFF;
        }

        result = sem_wait(sem);
        if (result != 0) {
            fprintf(stderr, "Failed to wait on semaphore with error %s\n", strerror(errno));
            exit(EXIT_FAILURE);
        }

        // Enter transmit mode only if not already in receive mode
        if (currentState != TxState) {
            retVal = mode_tx();
            if (retVal != AXRADIO_ERR_NOERROR) {
                fprintf(stderr, "ERROR: Unable to enter TX mode\n");
                exit(EXIT_FAILURE);
            }
            currentState = TxState;
        }

        //printf("INFO: Sending another packet...\n");
        //printf("DEBUG: msg_length = %d\n", msg_length);
        //printf("DEBUG: reserved_space = %d\n", reserved_space);
        retVal = transmit_packet(&remoteaddr_tx, packet, (uint16_t)(msg_length + reserved_space));
        if (retVal != AXRADIO_ERR_NOERROR) {
            fprintf(stderr, "ERROR: Unable to transmit a packet\n");
            exit(EXIT_FAILURE);
        }

        result = sem_post(sem);
        if (result != 0) {
            fprintf(stderr, "Failed to post on semaphore with error %s\n", strerror(errno));
            exit(EXIT_FAILURE);
        }

	usleep(200000);
    }

    return NULL;
}

size_t get_message(uint8_t *buffer, size_t avail) {

    static int instructionsPrinted = 0;

    // obtain a line of text. We state the message is limited to avail-2 to
    // leave space for the newline and the null terminator
    if (!instructionsPrinted) {
        printf("Please enter your message, up to %d characters\n   (empty message to terminate the program):\n", (int)(avail-2));
        instructionsPrinted = 1;
    }
    fgets((char *)buffer, (int)avail, stdin);

    // check for end-of-file (for redirecting stdin)
    if (feof(stdin)) {
        buffer[0] = '\n';
        buffer[1] = 0;
    }

    // If the newline isn't present, the message is too long

    //printf("DEBUG: ***%s***\n", buffer);

    if (buffer[strlen((char *)buffer) - 1] != '\n') {
        buffer[strlen((char *)buffer) - 1] = '\n';
        printf("WARNING: message too long. It will be truncated to\n%s", (char *)buffer);

        // If the newline isn't in the buffer, read characters from the keyboard buffer to the newline
        int c;
        do {
            c = getchar();
        } while (c != '\n' && c != EOF);
    }

    //printf("DEBUG: ***%s***\n", buffer);

    return strlen((char *)buffer);
}

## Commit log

2018-11-03 Fix the AX.25 PID (from 0x0f to 0xf0)
    [main.c]
2022-10-25 Add prototype 1.3.5 and 1.4 kicad files. These have not been assembled or tested
    [PiHatAx5043-B.Cu.gbl, PiHatAx5043-B.Mask.gbs, PiHatAx5043-B.SilkS.gbo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]

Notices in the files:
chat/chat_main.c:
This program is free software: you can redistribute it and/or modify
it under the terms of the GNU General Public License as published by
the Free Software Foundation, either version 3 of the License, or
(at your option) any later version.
